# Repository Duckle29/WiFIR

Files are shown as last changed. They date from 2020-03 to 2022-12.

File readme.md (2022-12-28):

# WiFI*R*

The WiFI*R* is a WiFi IR blaster / remote, based around a WeMos D1 mini (ESP8266)

[Firmware](https://github.com/Duckle29/wifir_firmware)  
The WiFIR was made from a need to control a heatpump / ac to allow pre-heating of a summer-house before arriving. It can however control anything IR controlled.

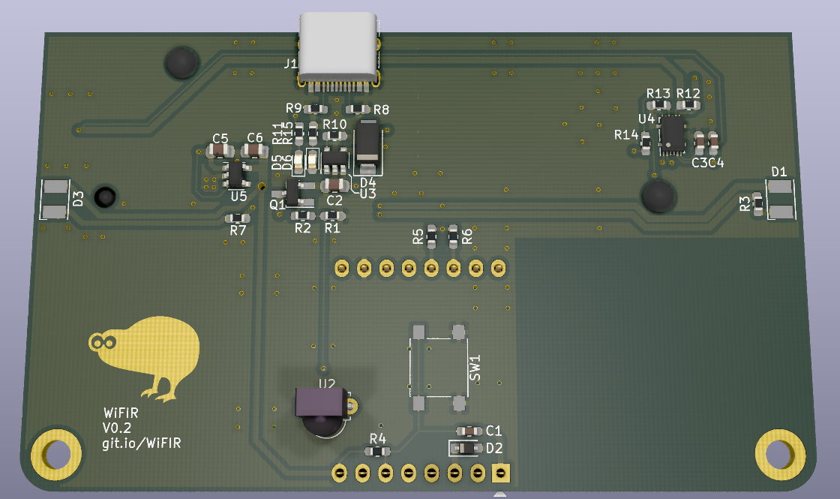
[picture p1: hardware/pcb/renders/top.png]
top render

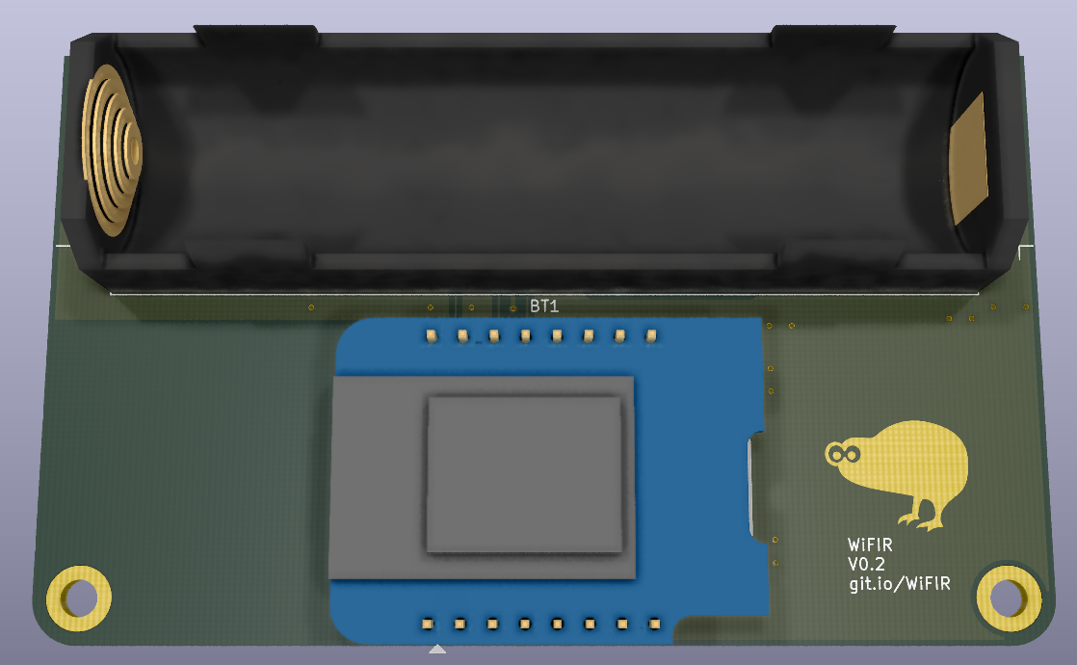
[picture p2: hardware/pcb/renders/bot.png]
bottom render


[Interactive BOM](https://WiFIR.github.io/pcb/ibom.html)

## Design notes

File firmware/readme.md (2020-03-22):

# WiFI*R* firmware

For now, this is just a skeleton firmware, with known-in-advance library dependencies added.

The firmware is written in the Arduino framework, through PlatformIO.

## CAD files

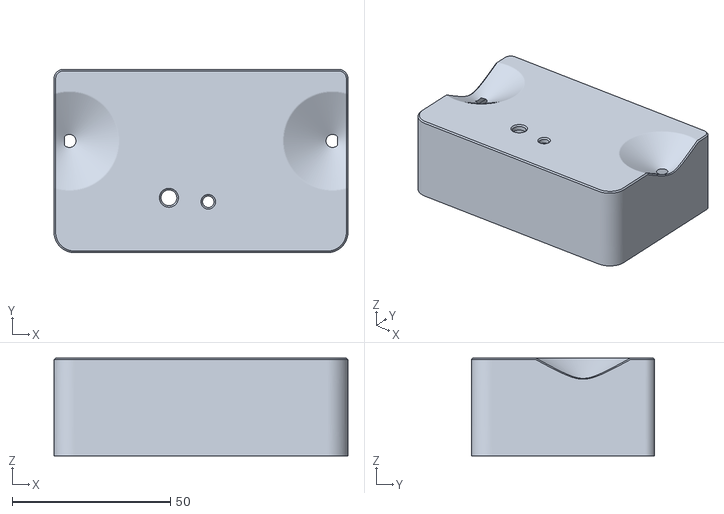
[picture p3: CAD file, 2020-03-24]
hardware/case/case.stl
93.0 x 58.0 x 31.0

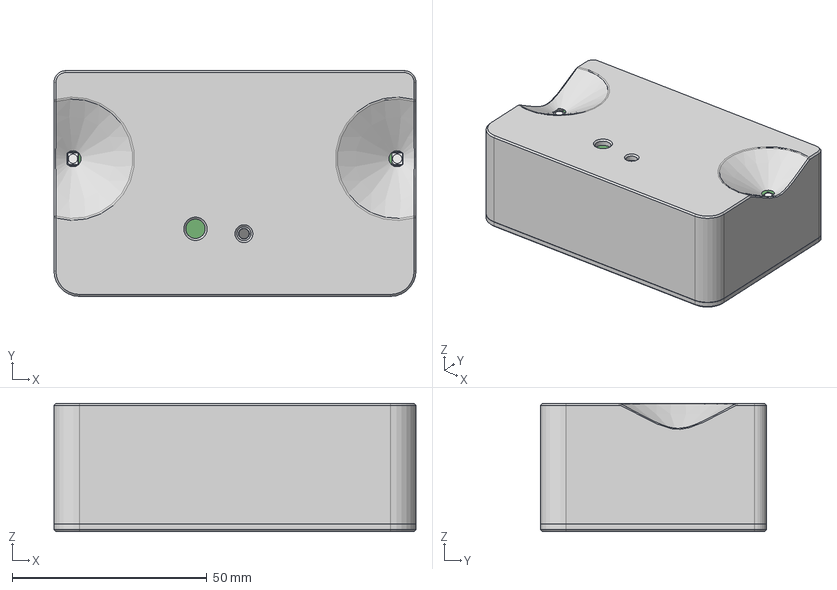
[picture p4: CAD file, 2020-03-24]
hardware/case/WiFIR case v9.step
93.0 x 58.0 x 33.0 mm
Backing Lid

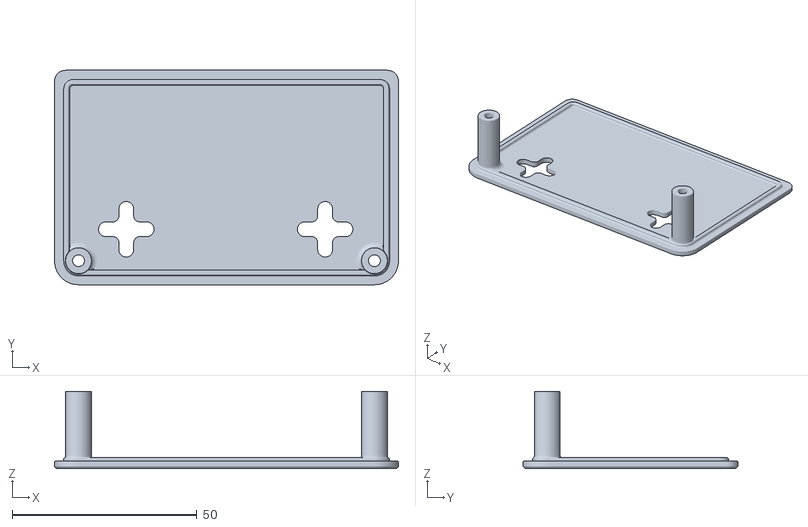
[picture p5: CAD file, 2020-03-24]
hardware/case/lid_wallplate.stl
93.0 x 58.0 x 20.9

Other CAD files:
hardware/case/WiFIR case v9.f3z

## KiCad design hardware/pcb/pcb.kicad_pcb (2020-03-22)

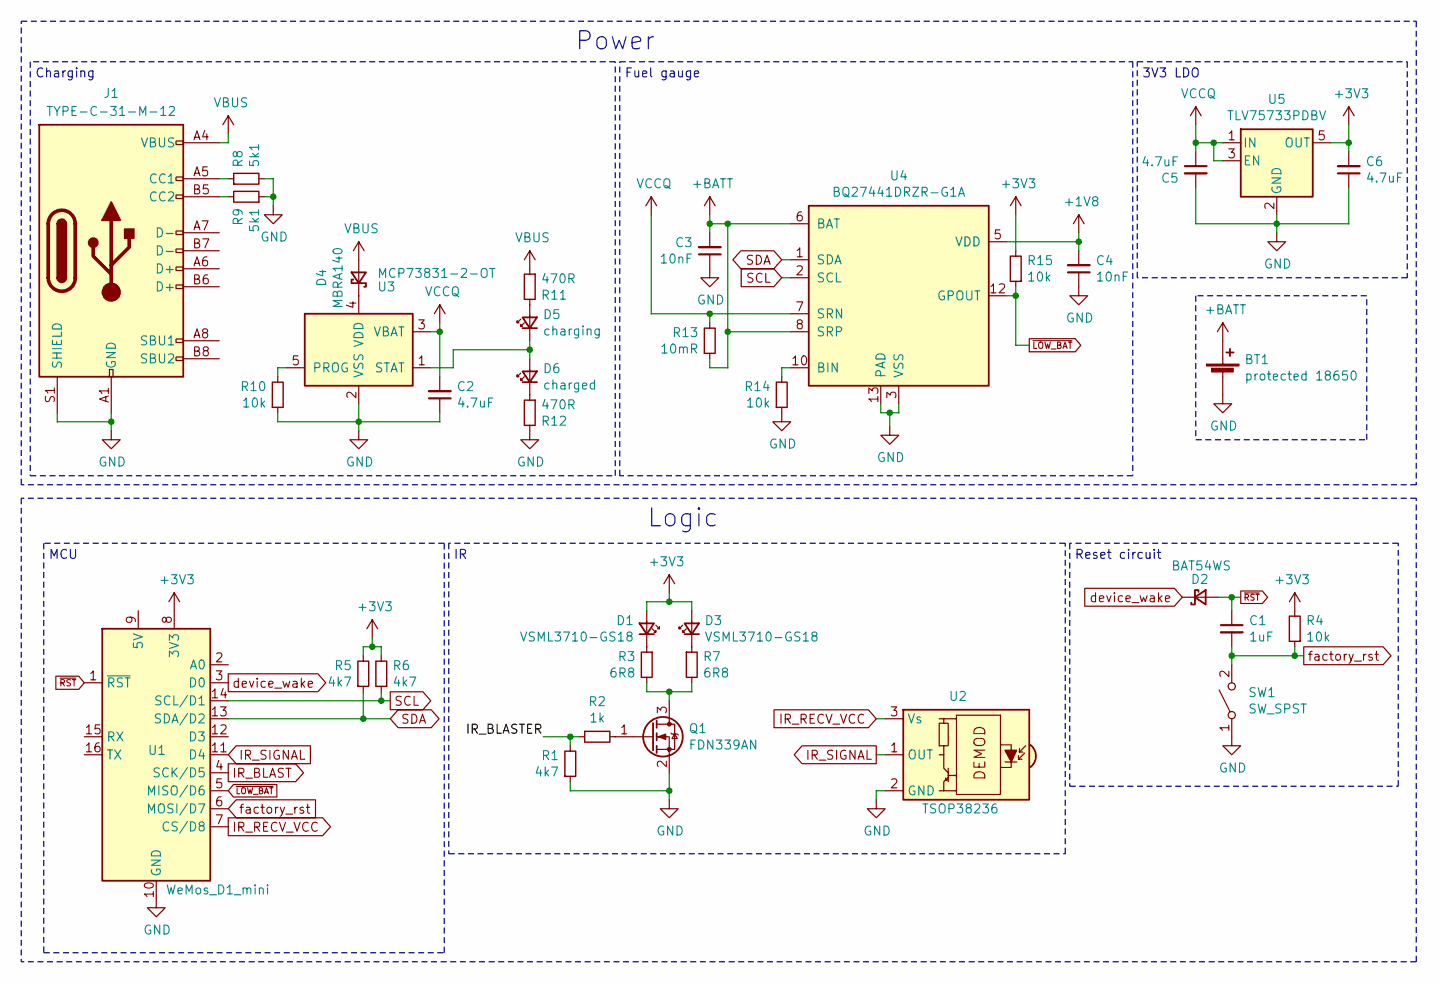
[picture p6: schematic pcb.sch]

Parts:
BT1: protected 18650; BatteryHolder_Keystone_1042_1x18650
C1: 1uF; C_0603_1608Metric_Pad1.05x0.95mm_HandSolder
C2, C5, C6: 4.7uF; C_0805_2012Metric_Pad1.15x1.40mm_HandSolder
C3, C4: 10nF; C_0603_1608Metric_Pad1.05x0.95mm_HandSolder
D1, D3: VSML3710-GS18; LED_PLCC-2
D2: BAT54WS; D_SOD-323_HandSoldering
D4: MBRA140; D_SMA
D5: charging; LED_0603_1608Metric_Pad1.05x0.95mm_HandSolder
D6: charged; LED_0603_1608Metric_Pad1.05x0.95mm_HandSolder
J1: TYPE-C-31-M-12; USB_C_Receptacle_HRO_TYPE-C-31-M-12
Q1: FDN339AN; SOT-23_Handsoldering
R1, R5, R6: 4k7; R_0603_1608Metric_Pad1.05x0.95mm_HandSolder
R2: 1k; R_0603_1608Metric_Pad1.05x0.95mm_HandSolder
R3, R7: 6R8; R_0603_1608Metric_Pad1.05x0.95mm_HandSolder
R4, R10, R14, R15: 10k; R_0603_1608Metric_Pad1.05x0.95mm_HandSolder
R8, R9: 5k1; R_0603_1608Metric_Pad1.05x0.95mm_HandSolder
R11, R12: 470R; R_0603_1608Metric_Pad1.05x0.95mm_HandSolder
R13: 10mR; R_0603_1608Metric_Pad1.05x0.95mm_HandSolder
SW1: SW_SPST; SW_Push_1P1T_NO_6x6mm_H9.5mm
U1: WeMos_D1_mini; WEMOS_D1_mini_light
U2: TSOP38236; Vishay_MINICAST-3Pin
U3: MCP73831-2-OT; SOT-23-5
U4: BQ27441DRZR-G1A; Texas_S-PDSO-N12
U5: TLV75733PDBV; SOT-23-5

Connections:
+1V8: C4.2, U4.5 (VDD)
+3V3: C6.2, D1.2 (A), D3.2 (A), R4.2, R5.2, R6.2, R15.2, U1.8 (3V3), U5.5 (OUT)
+BATT: BT1.1 (+), C3.2, R13.1, U4.6 (BAT), U4.8 (SRP)
/IR_BLASTER: R1.2, R2.1
GND: BT1.2 (-), C2.1, C3.1, C4.1, C5.2, C6.1, J1.A1 (GND), J1.A12 (GND), J1.B1 (GND), J1.B12 (GND), J1.S1 (SHIELD), Q1.2 (S), R1.1, R8.2, R9.1, R10.1, R12.2, R14.1, SW1.1 (A), U1.10 (GND), U2.2 (GND), U3.2 (VSS), U4.3 (VSS), U4.13 (PAD), U5.2 (GND)
IR_BLAST: U1.4 (SCK/D5)
IR_RECV_VCC: U1.7 (CS/D8), U2.3 (Vs)
IR_SIGNAL: U1.11 (D4), U2.1 (OUT)
unnamed: D1.1 (K), R3.1
unnamed: D3.1 (K), R7.1
unnamed: D4.1 (K), U3.4 (VDD)
unnamed: D5.1 (K), D6.2 (A), U3.1 (STAT)
unnamed: D5.2 (A), R11.2
unnamed: D6.1 (K), R12.1
unnamed: J1.A5 (CC1), R8.1
unnamed: J1.B5 (CC2), R9.2
unnamed: Q1.1 (G), R2.2
unnamed: Q1.3 (D), R3.2, R7.2
unnamed: R10.2, U3.5 (PROG)
unnamed: R14.2, U4.10 (BIN)
SCL: R6.1, U1.14 (SCL/D1), U4.2 (SCL)
SDA: R5.1, U1.13 (SDA/D2), U4.1 (SDA)
VBUS: D4.2 (A), J1.A4 (VBUS), J1.A9 (VBUS), J1.B4 (VBUS), J1.B9 (VBUS), R11.1
VCCQ: C2.2, C5.1, R13.2, U3.3 (VBAT), U4.7 (SRN), U5.1 (IN), U5.3 (EN)
device_wake: D2.1 (K), U1.3 (D0)
factory_rst: C1.2, R4.1, SW1.2 (B), U1.6 (MOSI/D7)
~LOW_BAT: R15.1, U1.5 (MISO/D6), U4.12 (GPOUT)
~RST: C1.1, D2.2 (A), U1.1 (~RST)

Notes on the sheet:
Logic
Power
3V3 LDO
Fuel gauge
Charging
MCU
Reset circuit

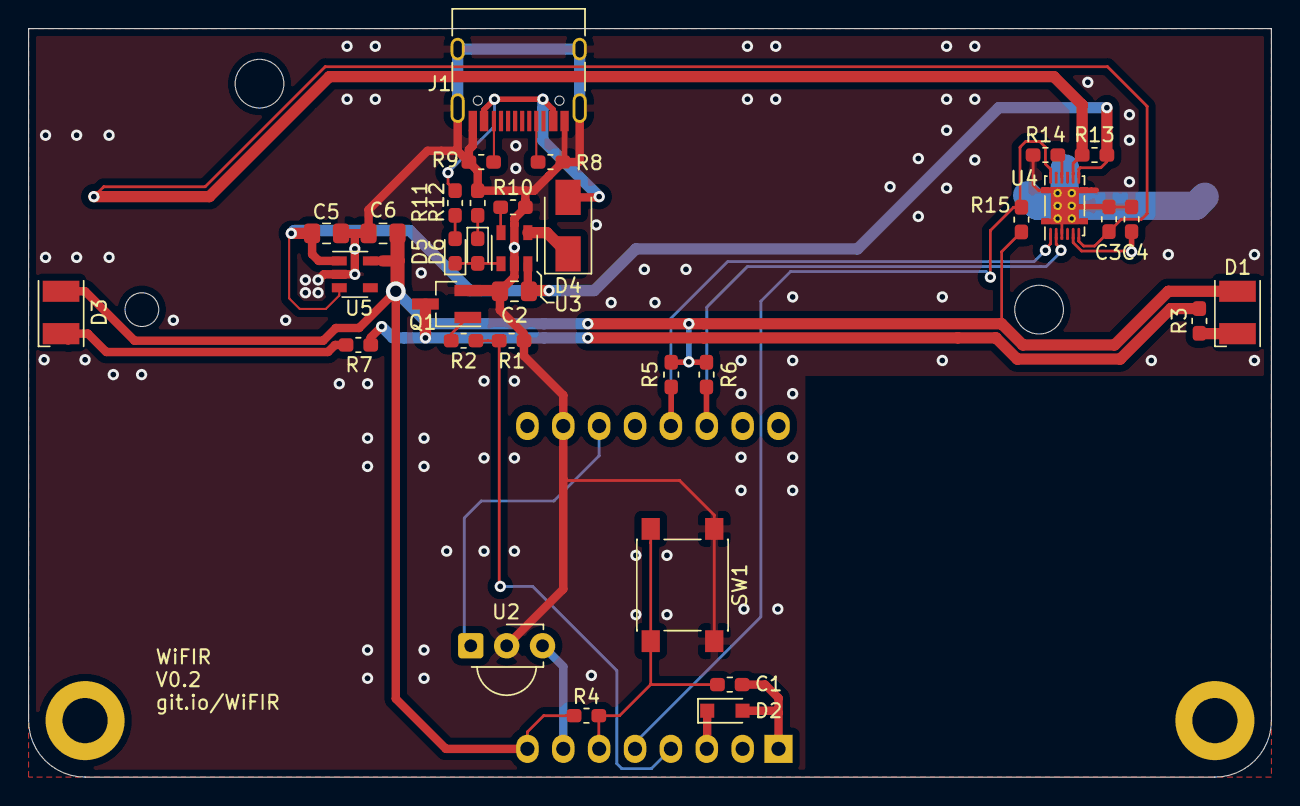
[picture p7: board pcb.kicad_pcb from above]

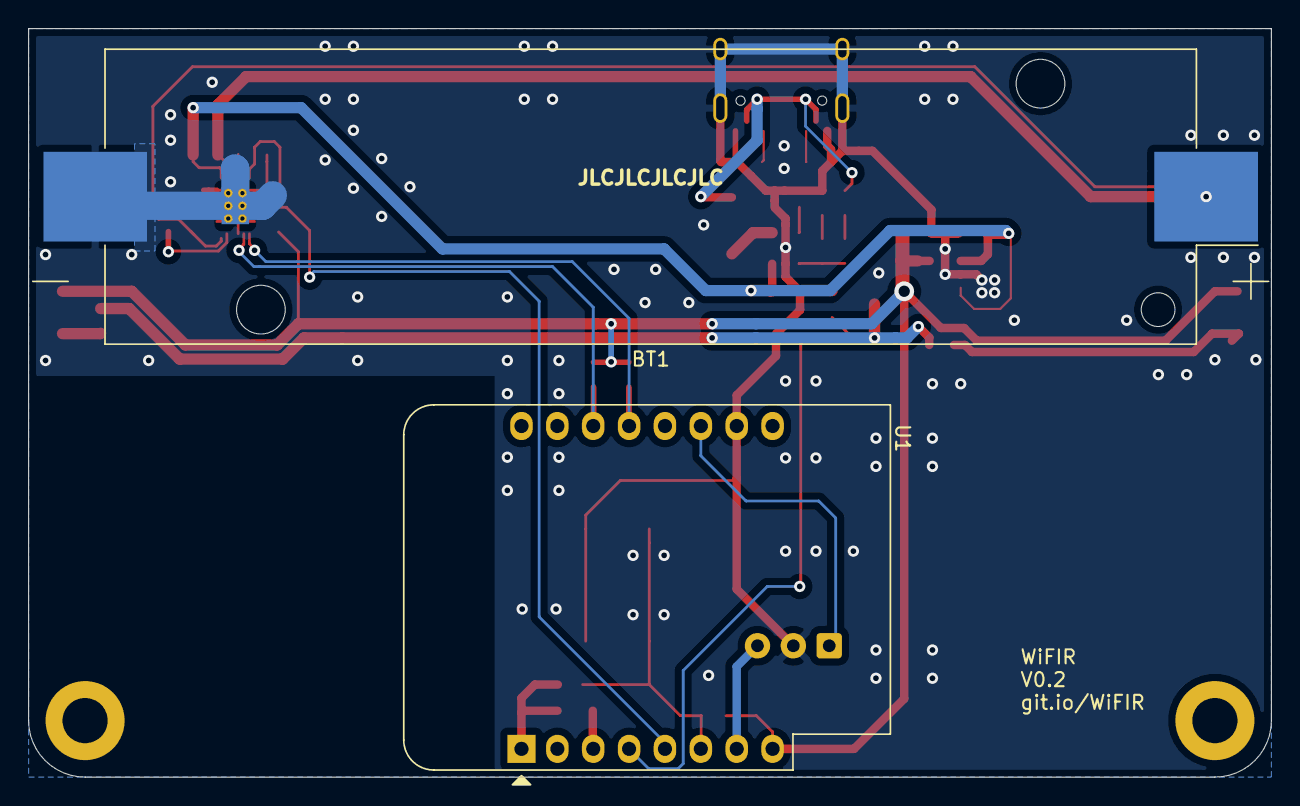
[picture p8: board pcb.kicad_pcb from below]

Board: 2 copper layers, 88.0 x 53.0 mm, 36 parts (2 on the bottom side), 27 nets.

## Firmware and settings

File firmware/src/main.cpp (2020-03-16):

#include "main.h"

#define CLEAR_PIN D7

void setup() {
  Serial.begin(115200);
  //schlep(5e6);
  WiFiManager wifiManager;

  pinMode(CLEAR_PIN, INPUT_PULLUP);
  delay(10);

  if(!digitalRead(CLEAR_PIN)) // If reset via clear pin
  {
    // Wait 5 seconds
    uint32_t delay_start = millis();
    while(!digitalRead(CLEAR_PIN) && millis() - delay_start > 5000)
    {
      delay(50);
    }
    // Ensure any button bounce has cleared in case the button was released prematurely.
    delay(10);

    // If button still held, clear WiFi settings.
    if(!digitalRead(CLEAR_PIN))
    {
      wifiManager.resetSettings();
    }
  }

  wifiManager.autoConnect("WiFIR");
}

void loop() {
  // put your main code here, to run repeatedly:
}


char * uintToStr( const uint64_t num, char *str )
{
  uint8_t i = 0;
  uint64_t n = num;
 
  do
    i++;
  while ( n /= 10 );
 
  str[i] = '\0';
  n = num;
 
  do
    str[--i] = ( n % 10 ) + '0';
  while ( n /= 10 );

  return str;
}

void schlep(uint64_t duration)
{
  char dur[21];
  uintToStr(duration, dur);
  Serial.println("Sleeping for " + String(dur) + "uS");
  ESP.deepSleepInstant(duration);
}

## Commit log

2020-03-16 updated renders
    [PowerManagement.sch, pcb.kicad_pcb, pcb.sch]
2020-03-21 Moved BQ fuelgauge to battery gnd terminal for thermal coupling
    [pcb.kicad_pcb]
2020-03-22 Added gerbers
2020-03-22 saved pcbnew
    [pcb.kicad_pcb]
2020-03-22 Added schematic
    [PowerManagement.sch, pcb.kicad_pcb, pcb.sch]
2020-03-24 Added case for v0.2
    [WiFIR case v9.f3z, WiFIR case v9.step, case.stl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]
